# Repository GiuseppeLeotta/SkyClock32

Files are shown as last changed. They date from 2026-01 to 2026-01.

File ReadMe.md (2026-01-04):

# SkyClock

> **Time, atmosphere and the sky — on your table**

A stylish desk clock that shows the time with an analog-digital dial, monitors temperature, humidity and atmospheric pressure, records 24-hour trends with intuitive charts, and indicates sunrise and sunset times as well as the position of the Moon and the main planets. All accompanied by a gentle cuckoo every hour and bells at noon.

<p align="center">
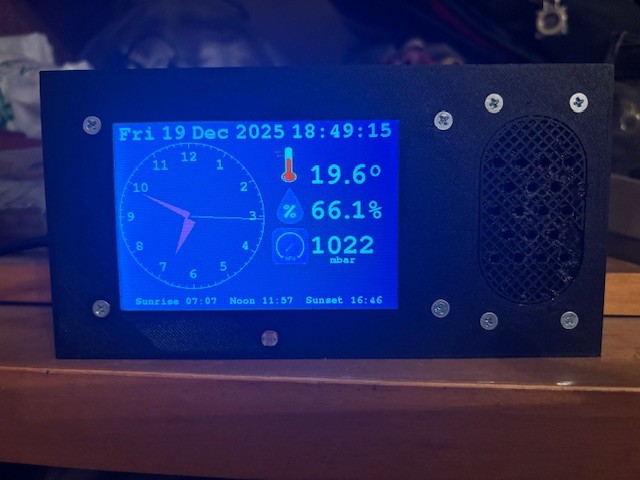
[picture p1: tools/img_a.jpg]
    
</p>

Bring to your table an object that tells the story of time and the sky. **SkyClock** combines a large, readable display with precision microclimate sensors and local astronomical calculations: sunrise/sunset times, the position of the Moon and the planets Mercury, Venus, Mars, Jupiter and Saturn. It records temperature, humidity and pressure trends over the last 24 hours and displays them with intuitive charts. A sweet cuckoo every hour; bells at noon. Set your preferred alarm and customize every aspect to your needs.

<p float="left" >
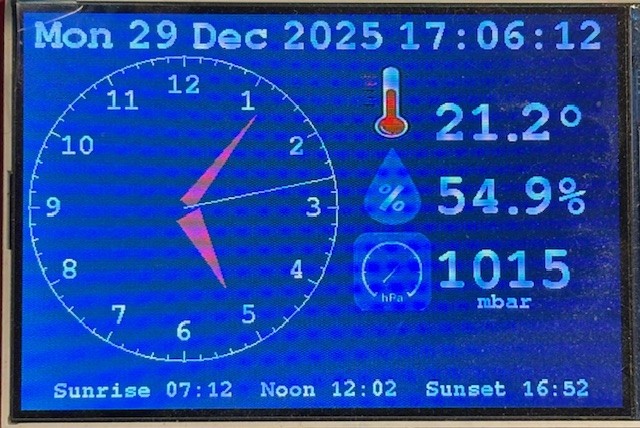
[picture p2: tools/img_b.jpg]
  
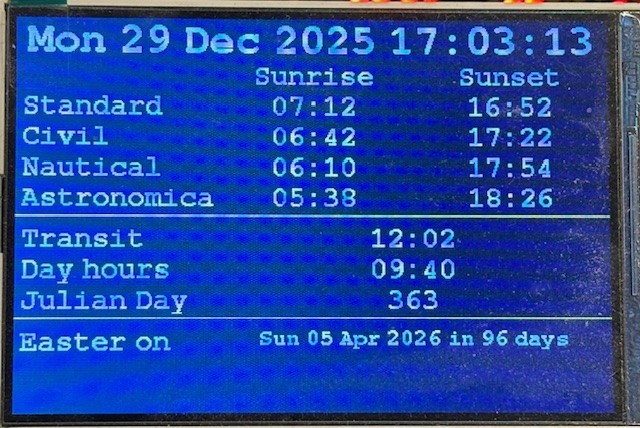
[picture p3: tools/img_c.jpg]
  
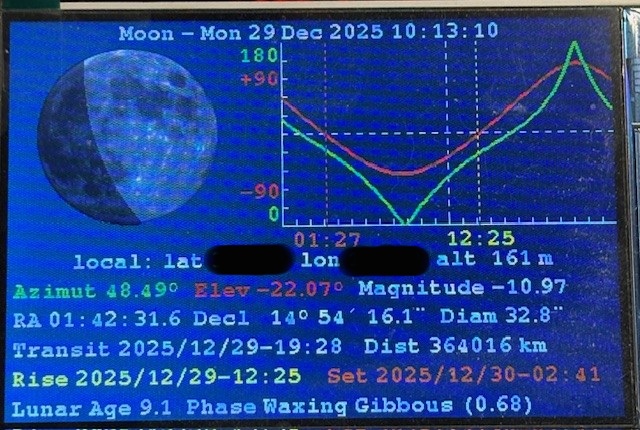
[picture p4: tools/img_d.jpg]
  
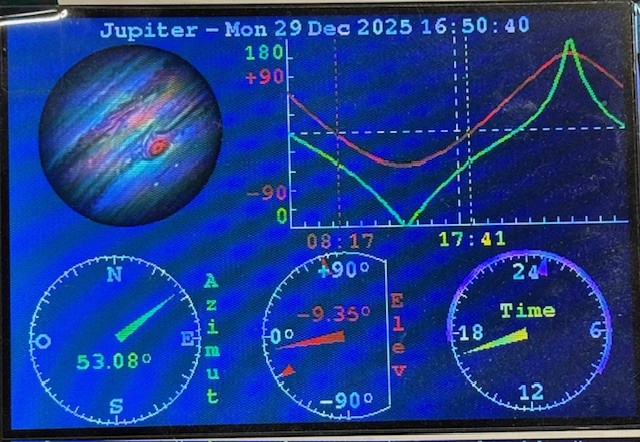
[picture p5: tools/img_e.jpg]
  
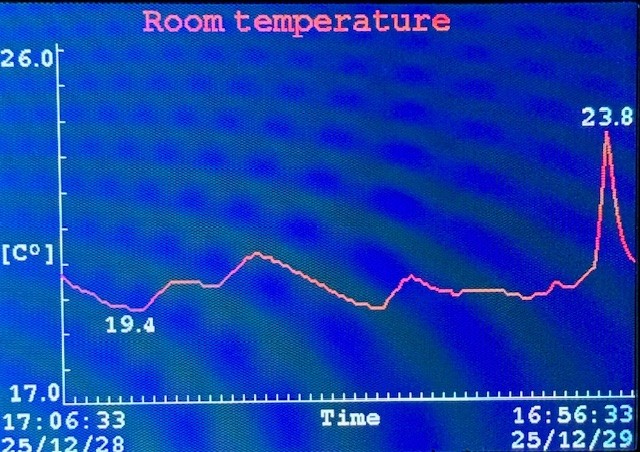
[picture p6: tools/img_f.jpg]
  
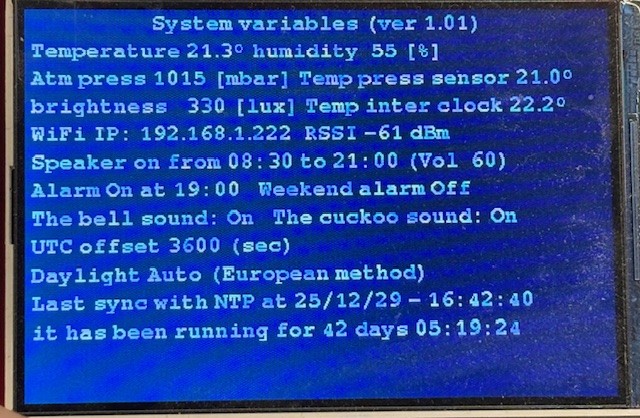
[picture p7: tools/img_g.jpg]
  
</p>

Here is a video showing what happens at noon; you will hear the bells ringing :smile:. Click on the image.

<p align="center">
  <a href="https://vimeo.com/1151204204" target="_blank" rel="noopener noreferrer">
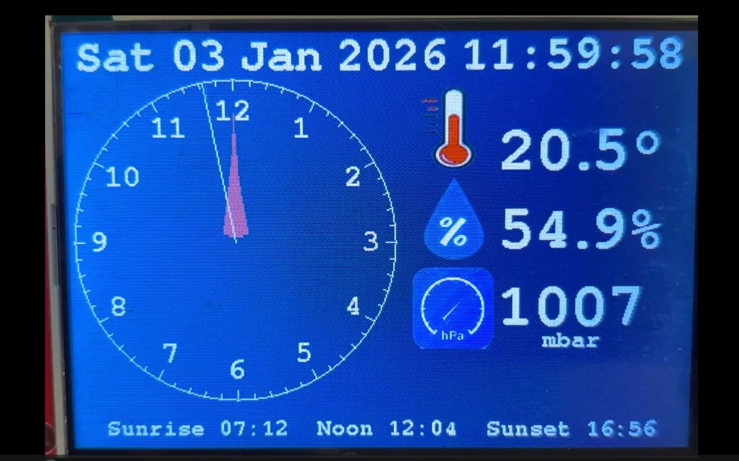
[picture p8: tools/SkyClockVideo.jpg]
SkyClockVideo — click to watch
    
  </a>
</p>

## Features

- **Main dial**: large analog-digital display with overlay readings of temperature, humidity and atmospheric pressure values.

- **Additional screens**: sunrise and sunset times and a simplified night sky map showing the position of the Moon and visible planets (Mercury, Venus, Mars, Jupiter, Saturn).

- **24h log**: automatic sampling and storage of environmental data with charts that can be viewed directly on the display.

- **Customizable chimes**: cuckoo every hour, bells at noon and configurable alarm. Sound activation options include the ability to disable the cuckoo during nighttime hours.

- **Setup via web server**: connect to **SkyClock** via WiFi and use your smartphone and a web browser to configure all parameters to your liking.

## Technical specifications

- **Display**: 4.0 Inch SPI TFT LCD Module 4.0" with ILI9488 driver, resolution 480×320 pixels and brightness control.
- **Sensors**: digital thermometer, hygrometer and precision barometer.
- **Memory**: rolling log of the last 24 hours, sampling every 30 seconds, storage every 10 minutes.
- **Astronomical calculation**: positions and times calculated locally from latitude and longitude. Calculation of sunrise/sunset, right ascension, declination, altitude, azimuth and magnitude. Moon phases with limb angle and parallax calculations.
- **Audio**: integrated speaker with cuckoo, bells and customizable alarm sounds; adjustable volume.
- **Power**: 5V adapter with backup battery to preserve the clock.
- **Connectivity**: WiFi, access point mode and automatic synchronization with NTP servers for maximum accuracy.

## Contents

- [Setup Guide](#setup-guide)
  - [List of Components](#list-of-components)
  - [Wiring](#wiring)
  - [Printed Circuit Board](#printed-circuit-board)
  - [3D Printer Box Creation](#3d-printer-box-creation)
- [Assembly](#assembly)
  - [Compilation](#compilation)
    - [FileSystem](#filesystem)
  - [How to assemble it](#how-to-assemble-it)
  - [Configuration](#configuration)
- [Warnings](#warnings)
- [Licensing](#licensing)
- [Disclaimer](#Disclaimer)

## Setup Guide

### List of Components

Here is the complete list of electronic components needed to build the project. The provided links are for indication only and to help you find the parts.

> ***WARNING***: the display must necessarily have the ILI9488 driver

| Component Type | Component | Link |
| --- | --- | --- |
| LCD TFT 4.0 inch | 4.0 inch SPI TFT LCD no touch screen 480×320 pixel color display _(1)_ | Available [here](https://it.aliexpress.com/item/1005006102051152.html) |
| SHT30 | Temperature humidity sensor | Available [here](https://it.aliexpress.com/item/1005006939280040.html) |
| MAX98357 | 3W Class D Amplifier Breakout Interface I2S Decoder DAC for Audio | Available [here](https://it.aliexpress.com/item/1005006711010527.html) |
| ESP32 | ESP32 38Pin CP2102 micro USB | Available [here](https://it.aliexpress.com/item/1005006351235505.html) |
| Speaker | PCS 3 Watt 8 Ohm Micro Speaker | Available [here](https://www.amazon.it/HUAREW-Altoparlante-interfaccia-JST-PH2-0-elettronici/dp/B0CRNZYW1R/) |
| DS3231 | AZDelivery Real Time Clock RTC DS3231 and Free Battery Included | Available [here](https://www.amazon.it/AZDelivery-Arduino-Raspberry-Microcontroller-AT24C32/dp/B076GP5B94/) |
| BMP180 | AZDelivery 3 x GY-68 BMP180 Barometric Pressure Sensor | Available [here](https://www.amazon.it/AZDelivery-Pressione-Barometrica-Raspberry-gratuito/dp/B07FRW7YTK/) |
| Button | 16mm Plastic Momentary Push Button Switch, Round Head Button | Available [here](https://www.amazon.it/QitinDasen-Interruttore-Pulsante-Momentaneo-Plastica/dp/B08GPFTJ4Q/) |
| PCB Connectors | 2.54mm Pitch 40 Pin Breakaway PCB Board | Available [here](https://www.amazon.it/Breakaway-Connettore-Intestazione-Connettori-Prototype/dp/B0DJ2MYFMB/) |
| GL5516 | Photoresistor 5 mm - 10 Lux: 5-10 kOhm, Dark Resistance: 0.5 MOhm | Available [here](https://www.amazon.it/qualit%C3%A0-GL5516-Light-Dependent-Resistor-Photoresistor/dp/B00NXW9WZ6/) |
| 4 resistors | 1/4 watt: n.2 → 4,7 kOhm, n.1 → 47 kOhm, n.1 → 10 kOhm | |
| Capacitor | 1000µF 16 Volt capacitor | |

_(1) Note: it is listed as driver ST7796S but actually mounts the ILI9488 chip_

### Wiring

Here is the complete electrical schematic for the project. Building it is relatively simple, but if you decide to wire it manually without using the PCB, pay close attention to component polarities to avoid damage.

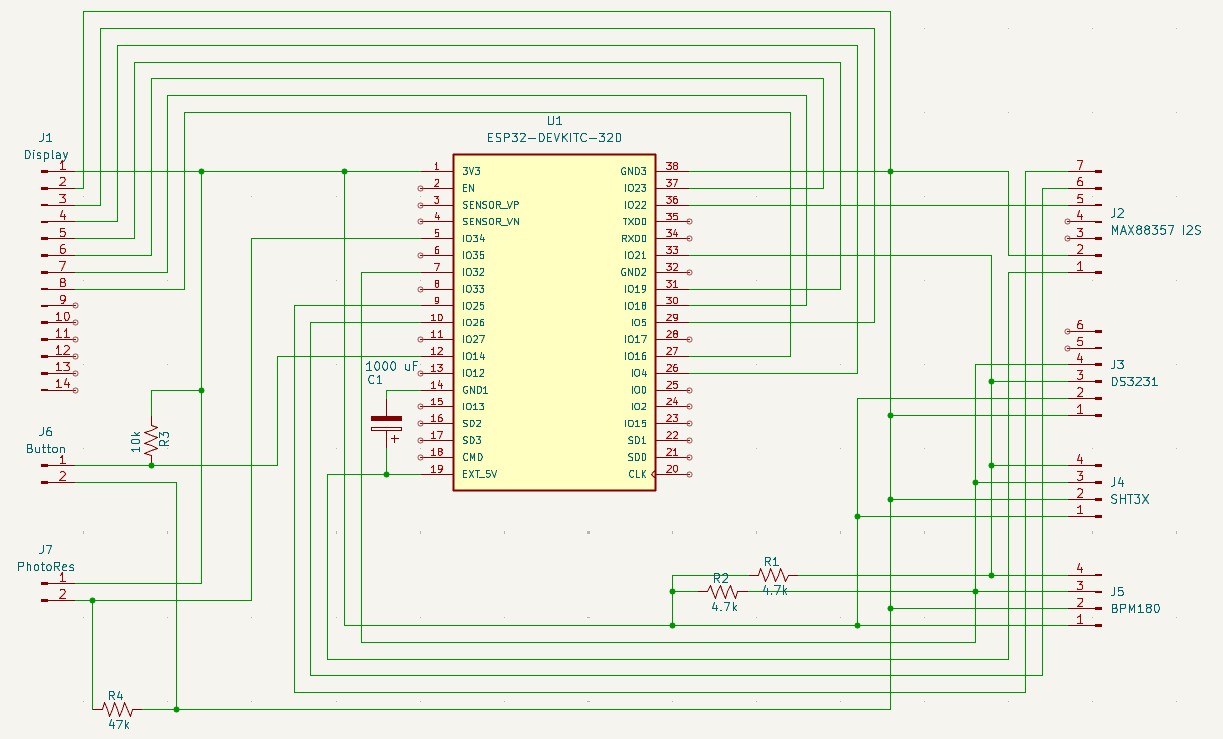
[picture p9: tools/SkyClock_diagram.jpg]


### Printed Circuit Board

The files needed to make the printed circuit board are available in this [folder](pcb/).

The printed circuit board is designed as a double-sided board. Pads were added for electrical connection between the Front and Back sides, making it possible to make the PCB even at home using a CNC milling machine. I personally use [FlatCAM](http://flatcam.org/) to generate .nc files to send to the CNC machine.

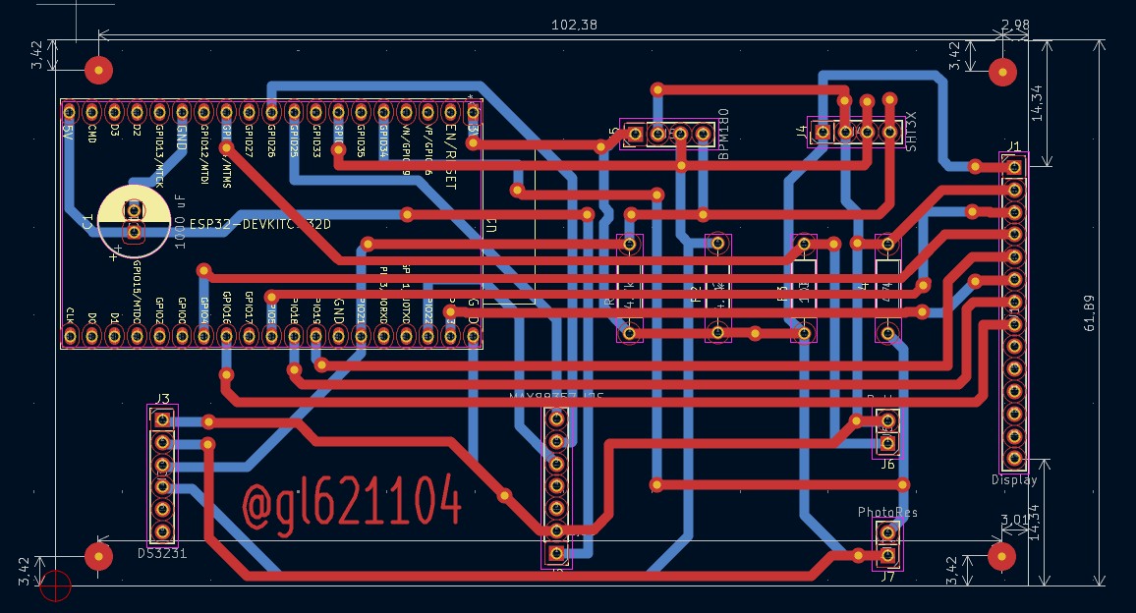
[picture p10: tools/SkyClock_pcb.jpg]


**Important note**: the PCB is prepared for soldering the display on the Front side. In this way the holes for supporting the PCB match exactly the holes of the display and those foreseen in the enclosure made with the 3D printer.

### 3D Printer Box Creation

To complete the project I designed an enclosure with [FreeCAD](https://www.freecad.org/) sized 165×85×45 mm to be made with a 3D printer. The enclosure was designed to perfectly host the PCB with the display connected, as you can see in the section [How to assemble it](#how-to-assemble-it).

<p float="left" >
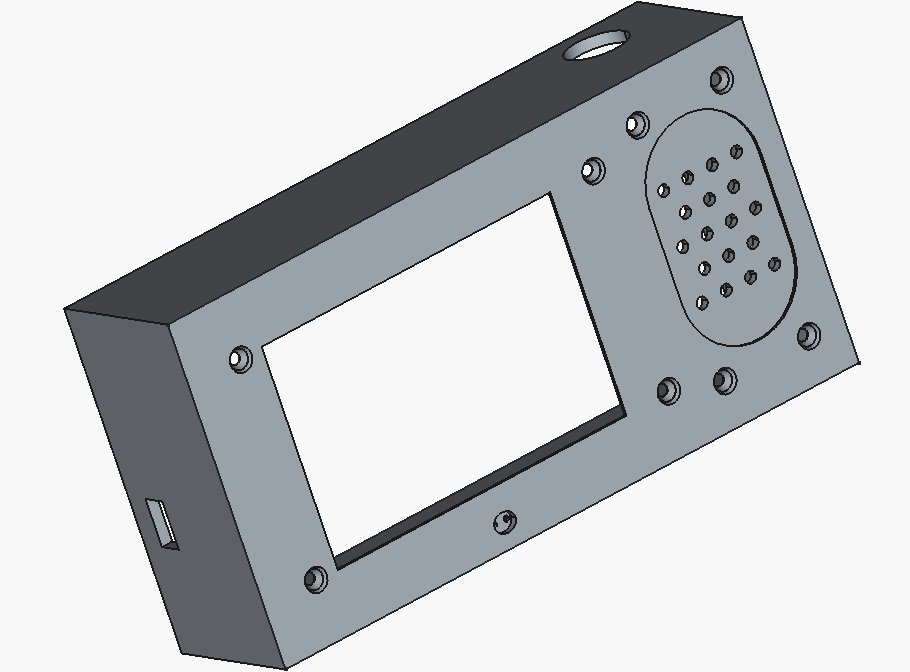
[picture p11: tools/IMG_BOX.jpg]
  
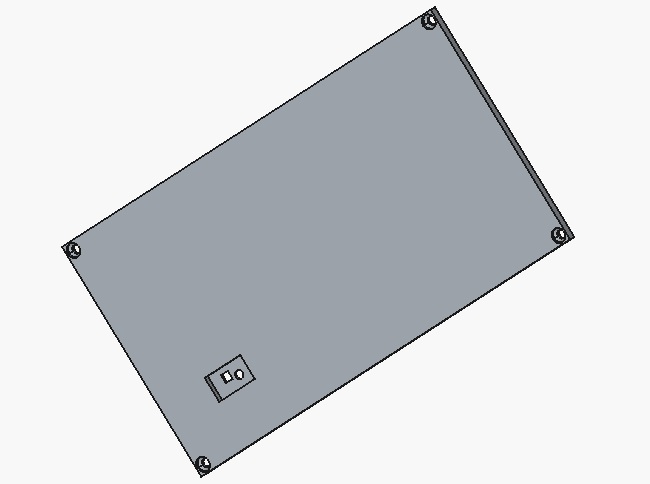
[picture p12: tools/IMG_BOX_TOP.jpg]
  
</p>

The .stl files are available in this [folder](print3d/). There are no particular criticalities in printer setup. I used the following settings with [Cura](https://ultimaker.com/software/ultimaker-cura/):

- Generic PLA
- 0.4 mm Nozzle
- Infill Density 30%
- Infill Pattern Cubic
- Support On
- Adhesion Off

The only important precaution is to enable supports (Support On) to avoid problems when creating the holes.

## Assembly

### Compilation

To compile the **SkyClock** software you need to have the [Arduino 2.x](https://docs.arduino.cc/software/ide-v2/tutorials/getting-started/ide-v2-downloading-and-installing/) IDE installed. First install support for ESP32. I recommend this tutorial: [Installing ESP32 Board in Arduino IDE 2](https://randomnerdtutorials.com/installing-esp32-arduino-ide-2-0/)

Next you need to install the driver for uploading the FileSystem. Again I recommend this tutorial: [Arduino IDE 2: Install ESP32 LittleFS Uploader](https://randomnerdtutorials.com/arduino-ide-2-install-esp32-littlefs/)

The code requires the [ESP8266Audio](https://github.com/earlephilhower/ESP8266Audio) library created by [earlephilhower (Earle F. Philhower, III)](https://github.com/earlephilhower). To install it go to 'LIBRARY MANAGER', search for ESP8266Audio and proceed with the installation.

<p align="center">
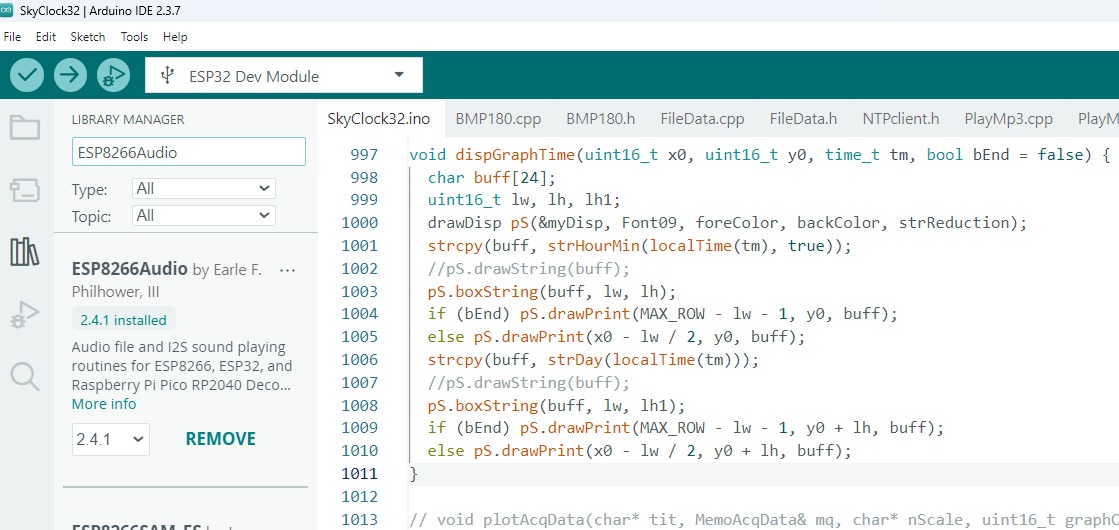
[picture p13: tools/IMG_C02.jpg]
  
</p>

Now we can proceed with compilation. Load the SkyClock32.ino file from the [SkyClock32](SkyClock32/) folder, select the board "ESP32 Dev Module" and Partition Scheme: "No OTA (2MB APP/2MB SPIFFS)".

<p align="center">
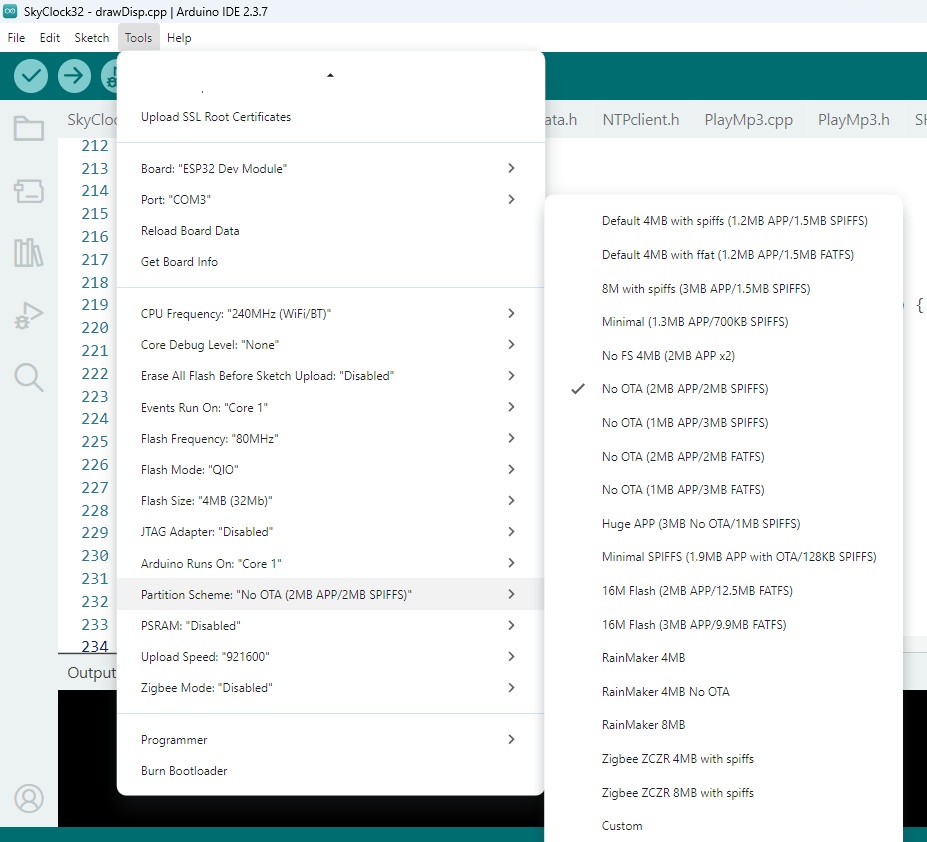
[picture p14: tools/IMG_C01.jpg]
  
</p>

At this point we can upload the data to the ESP32 filesystem (on Windows press [Ctrl] + [Shift] + [P]). All files present in the [data](SkyClock32/data) folder will be copied to the ESP32. After this step, compile and upload the program. Your **SkyClock** is ready to use!

#### FileSystem

In the [data](SkyClock32/data) folder are the files that will be copied into the ESP32 FileSystem. These are mainly .mp3 files for the noon bell sounds. There are 31 files that will be chosen randomly, one different for each day of the month, and then repeat the next month again randomly.

Of course you can change or add the sounds you prefer. The file name is not important (maximum 16 characters) but the extension must necessarily be .mp3. To avoid overloading the ESP32 memory it is recommended that files be mono with sampling at 8 kbps.

There is also the subfolder [as](SkyClock32/data/as) which contains 3 mp3 files. In this case the file naming is significant. You can modify their names inside the SkyClock32.ino code through the following constants:

```c
#define NAME_FILE_CUCU_PLAY "/as/CUCUCLK.mp3"
#define NAME_FILE_ALARM_CLOCK "/as/alarmClock1.mp3"
#define NAME_FILE_INIT_SOUND "/as/InitSound.mp3"
```

In particular these mp3 files are used for:

- `NAME_FILE_CUCU_PLAY` → plays the cuckoo every hour
- `NAME_FILE_ALARM_CLOCK` → is the alarm sound
- `NAME_FILE_INIT_SOUND` → is played only when **SkyClock** is turned on and is used to verify that the audio system is functioning correctly

### How to assemble it

Once the PCB and the enclosure have been made and all components soldered, we can proceed with final assembly. Get 3 mm screws with matching nuts. Length is not critical, just make sure it is longer than 10 mm (I used 15 mm screws). Also required are 4 screws of 30 mm which will be used to secure the display and the PCB.

The first component to mount is the speaker. The operation is not particularly difficult, but pay attention to the screws near the edges of the enclosure.

<p align="center">
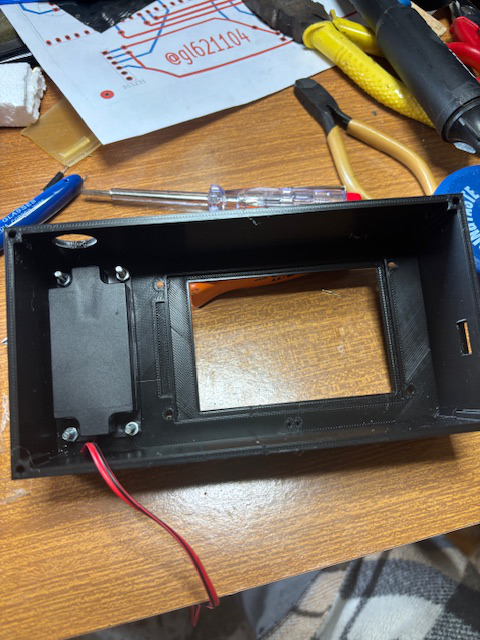
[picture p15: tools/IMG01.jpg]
    
</p>

Next mount the photoresistor. First cut the component leads to the right height (about halfway) so they can be inserted into the appropriate holes. If you prefer, you can simply solder them directly. A bit of adhesive tape will give stability to the connection.

<p align="center">
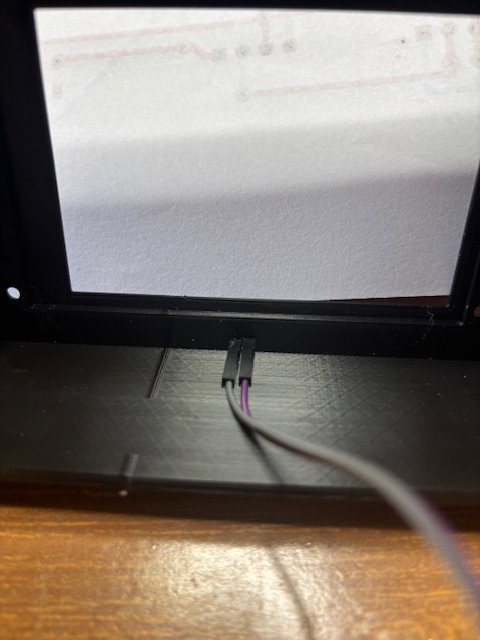
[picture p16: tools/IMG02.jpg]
  
</p>

Proceed with mounting the button, having previously soldered the electrical contacts. Pay attention during screwing, the nut is close to the speaker. Do not overtighten.

<p align="center">
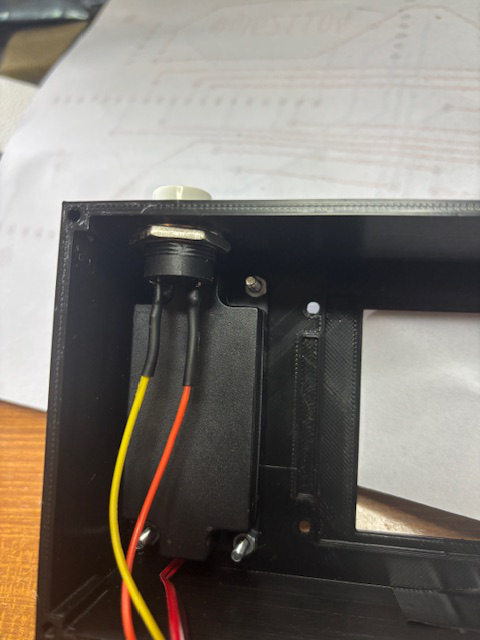
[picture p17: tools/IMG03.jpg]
    
</p>

Now move on to the most delicate part of the assembly. Use the 30 mm screws and insert the display so that the connectors face the speaker. Screw everything without over-tightening, leaving a small amount of play.

<p align="center">
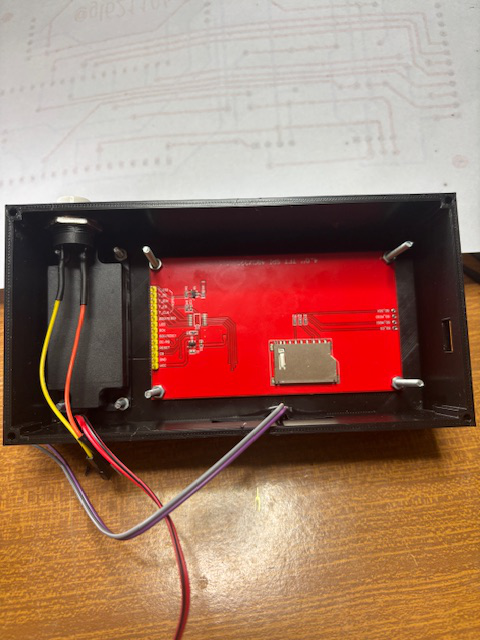
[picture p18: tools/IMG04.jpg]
    
</p>

Insert 4 nuts on the 30 mm screws, positioning them so they are perfectly flat and at the correct height to allow the display connectors to latch onto the PCB.

<p align="center">
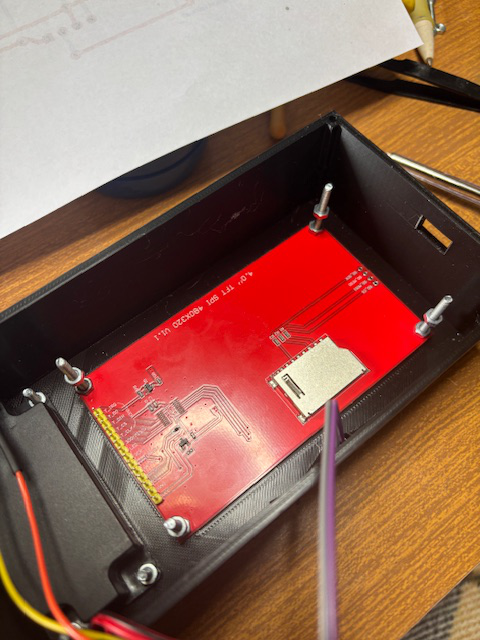
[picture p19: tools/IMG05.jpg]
    
</p>

At this point insert the PCB and attach the display. Check that the ESP32 mini-USB connector is perfectly aligned with the side hole of the enclosure so that the USB cable can be easily inserted. Secure everything with 4 more nuts.

<p align="center">
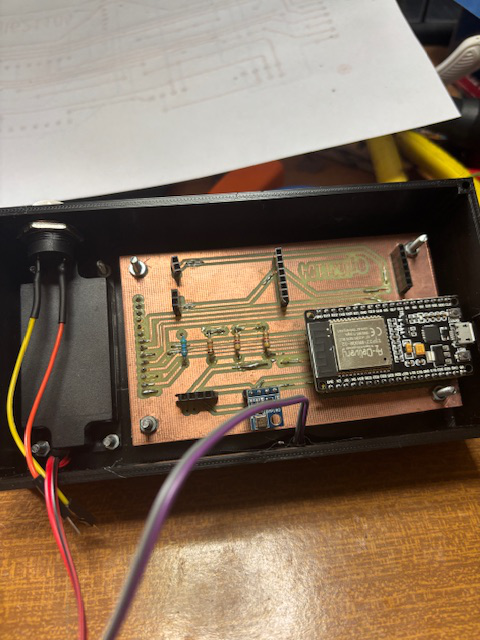
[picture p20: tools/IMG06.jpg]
  
</p>

Proceed to mount the SHT30 sensor in the enclosure lid. The grooves on the surface guide the insertion of the SHT30 into a single correct position. Fasten everything with a 10 mm screw.

<p align="center">
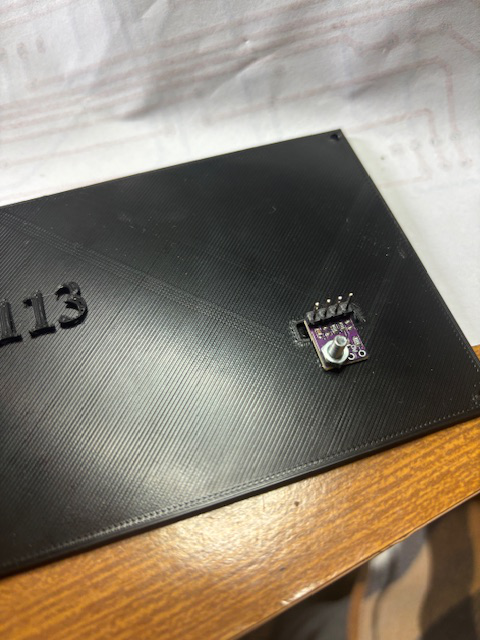
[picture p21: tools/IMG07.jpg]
    
</p>

If you want more accurate readings, you can insert a strip of expanded polystyrene to isolate the SHT30 sensor from the internal heat of the enclosure, making measurements more accurate.

<p align="center">
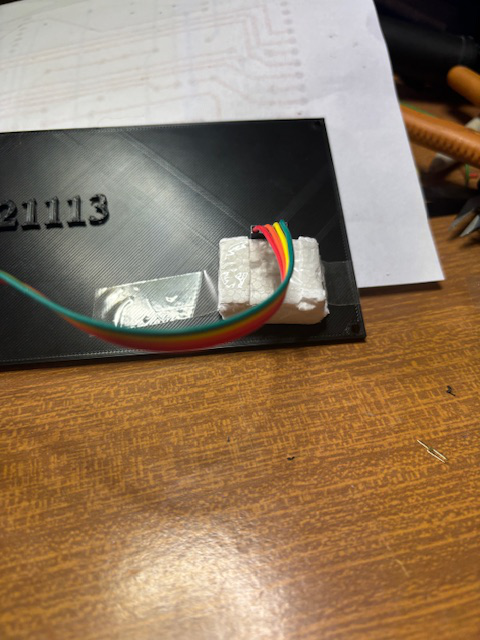
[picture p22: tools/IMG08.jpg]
  
</p>

Complete the assembly by making the final connections, paying **close attention to component polarities** to avoid damage.

<p align="center">
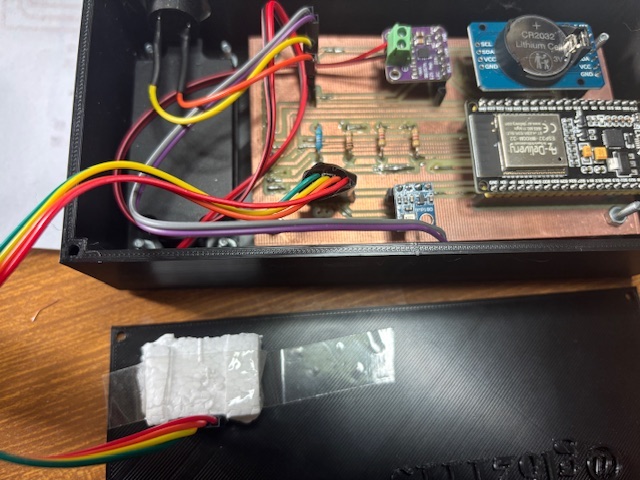
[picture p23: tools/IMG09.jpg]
    
</p>

### Configuration

There are two modes to configure **SkyClock**. The first allows you to change some parameters during normal operation using the built-in button. The second turns the ESP32 into a WiFi access point: by connecting to the network with SSID 'SkyClock' via a browser, you can configure all necessary parameters in a complete and intuitive way.

If we hold the button for at least 20 seconds, we enter the edit mode [Set Value](#set-value) to quickly change some parameters. To change the value of the selected variable (highlighted in green) just press the button quickly. To move to the next variable, hold the button a little longer. To go back continue holding the button, and to exit the edit screen continue holding it until the home screen is restored. The system may seem complicated to describe, but I assure you it is very intuitive to use! :smiley:

If we keep the button pressed for at least 30 seconds, we enter [Access point](#access-point) mode. In this case you will need to use a device such as a smartphone or tablet to access the full configuration interface.

#### Set Value

<p align="center">
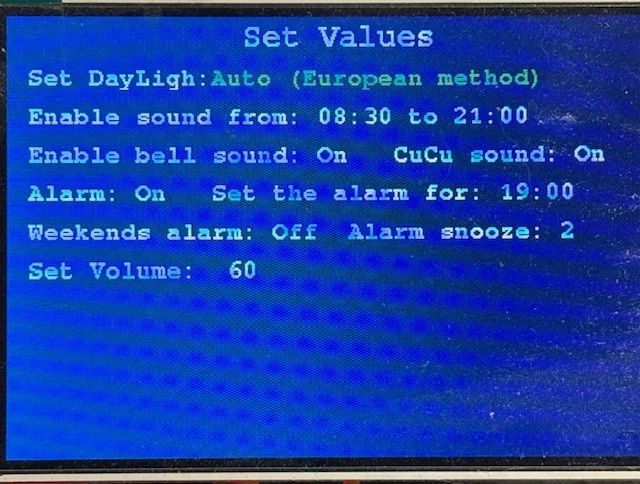
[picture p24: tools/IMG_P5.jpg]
  
</p>

Let's see the meaning of the available fields:

##### Set DayLight

Select daylight saving time handling. Three options are provided: the first enables automatic switching between standard/summer time according to the rules of the European Community, the other two allow manual enable/disable of daylight saving time.

##### Enable sound

Enables sounds for the selected time span. This function allows, for example, disabling the cuckoo during nighttime hours while keeping it active only during the day. The alarm is not affected by this setting and will ring at the scheduled time regardless.

##### Enable bell sound

Enables the noon bell sound every day. This function depends on the [Enable sound](#enable-sound) flag.

##### Cuckoo Sound

Enables the cuckoo sound every hour. This function also depends on the [Enable sound](#enable-sound) flag.

##### Alarm

Enables or disables the alarm.

##### Set the alarm for

Sets the alarm time.

##### Weekend alarm

Enable the alarm during the weekend. If you prefer not to be disturbed on Saturday and Sunday, set this flag to off.

##### Alarm snooze

Defines the number of times the alarm is automatically repeated. If you have difficulty waking up in the morning, increase this parameter! :smirk: In any case, the alarm sound can be stopped manually by pressing the button.

##### Set Volume

This parameter defines the sound volume. The range is 0 to 200. Keep in mind that at the maximum value of 200 the sound saturates. The recommended ideal value is 100.

#### Access point

After holding the button for at least 30 seconds, the following screen will appear on the display:

<p align="center">
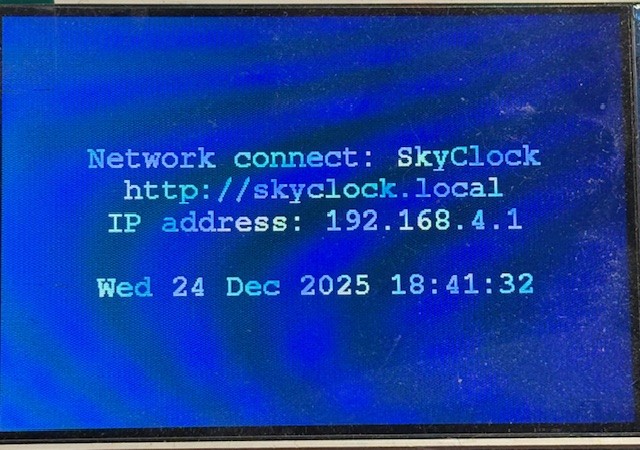
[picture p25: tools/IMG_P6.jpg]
  
</p>

Connect with the WiFi of your tablet or smartphone to the network with SSID **SkyClock** (no password required). Using one of the available browsers, type skyclock.local or, if you prefer, the direct IP address: 192.168.4.1. You will get the following configuration interface:

<p float="left" >
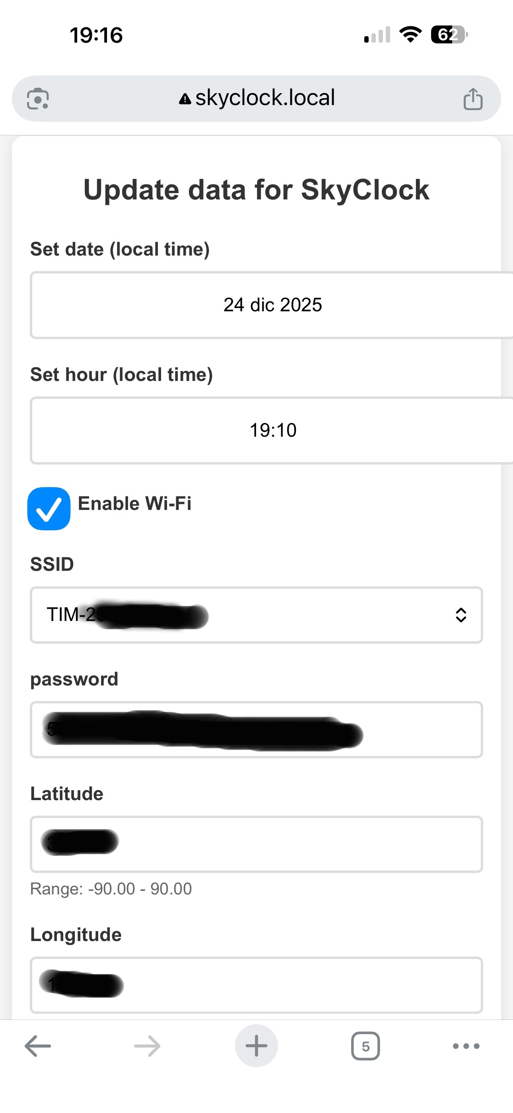
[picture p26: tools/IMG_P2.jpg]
  
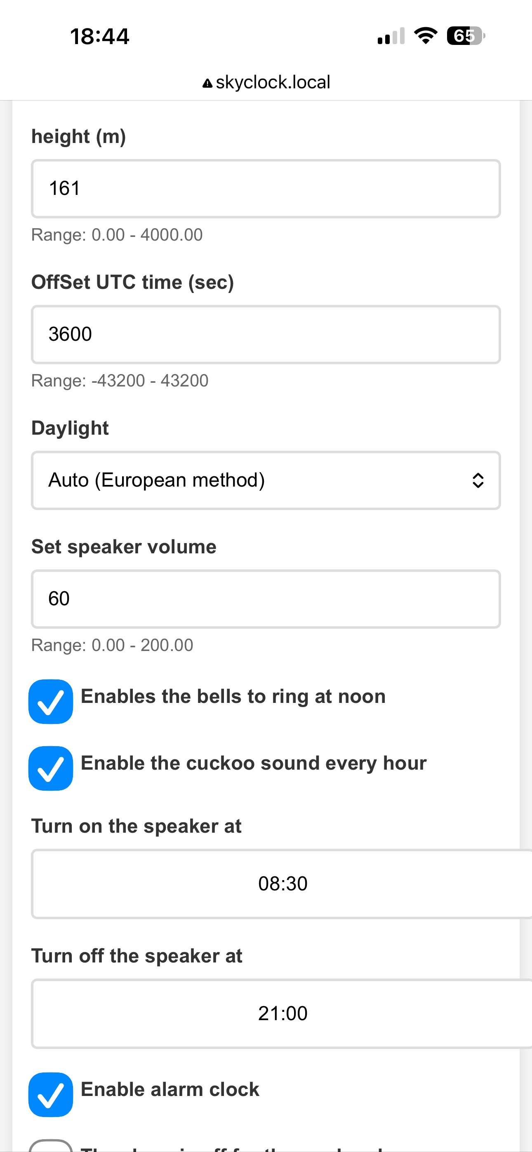
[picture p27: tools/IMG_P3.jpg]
  
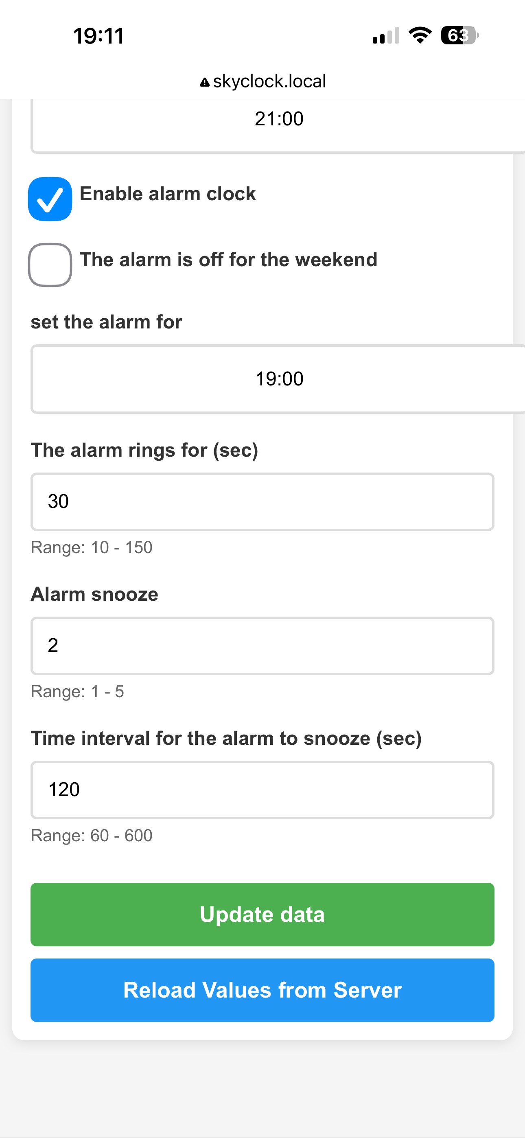
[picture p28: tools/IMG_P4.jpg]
  
</p>

Let's see the meaning of the available parameters:

##### Set Date - Set Hour

Set the local date and time manually. If the [Enable Wi-Fi](#enable-wi-fi) flag is disabled, the internal clock of **SkyClock** will be configured with these manually entered values.

##### Enable Wi-Fi

Enables WiFi connection. This function is used to automatically connect **SkyClock** to NTP (Network Time Protocol) servers approximately every 24 hours, ensuring maximum time precision. If you do not have a WiFi network, disable this flag: **SkyClock** accuracy will still be maintained by the DS3231 RTC module.

##### SSID - password

These are the parameters required to connect to your home WiFi network. If the [Enable Wi-Fi](#enable-wi-fi) flag is disabled, these values will not be considered.

##### Latitude - Longitude - height

These parameters define the precise geographic location where **SkyClock** is located. All astronomical calculations (sunrise, sunset, position of Moon and planets) use these values. Pay attention to extreme latitude values: beyond ±83 degrees astronomical calculations may present significant errors.

##### Offset UTC time

This parameter defines the difference in seconds between local time and Coordinated Universal Time (UTC). All astronomical calculations are performed using UTC and then converted to local time through this parameter and the [Set DayLight](#set-daylight) flag value. For example, if you live in Rome, which is one hour ahead of UTC, the value to enter is 3600 (i.e. one hour expressed in seconds).

##### The alarm ring for

This parameter defines the maximum duration in seconds of the alarm sound before it turns off automatically.

##### Time interval for the alarm to snooze

This parameter specifies the time interval in seconds between one alarm repetition and the next. The total number of repetitions is defined by the [Alarm snooze](#alarm-snooze) parameter.

##### Other Parameters

These parameters have already been described in detail in the [Set Value](#set-value) section. Here is the complete list of correspondences:

- Daylight → [Set DayLight](#set-daylight)
- Set Speaker volume → [Set Volume](#set-volume)
- Enables the bells to ring at noon → [Enable bell sound](#enable-bell-sound)
- Enable the cuckoo sound every hour → [Cuckoo Sound](#cuckoo-sound)
- Turn on/off the speaker at → [Enable sound](#enable-sound)
- Enable alarm clock → [Alarm](#alarm)
- The alarm is off for the weekend → [Weekend alarm](#weekend-alarm)
- Set alarm for → [Set the alarm for](#set-the-alarm-for)
- Alarm snooze → [Alarm snooze](#alarm-snooze)

## Warnings

Building this project requires a minimum of experience with embedded systems. It's not exceptionally complicated, but you need to be familiar with using a soldering iron and the basic principles of electronics. :grinning:

The code may contain errors which I will correct as they are found. I invite you to report any problems or bugs through the repository issues.

Astronomical calculations are performed with good accuracy, although a margin of error of a couple of minutes on sunrise and sunset times should be considered normal and acceptable. Pay special attention for extreme latitudes beyond ±83 degrees: I have not been able to carry out extensive tests at these latitudes, so there is a remote possibility that some algorithms diverge or that calculation precision is not sufficient. For reference, the Svalbard islands are at about 78 degrees North... do you know anyone who lives further north? :wink:

The code development was done in my spare time, so it has not been developed continuously. This inevitably led to different approaches in writing the code. I apologize if the result appears fragmented, not sufficiently commented, or if you find Italian comments scattered here and there.

## Licensing

This program is free software: you can redistribute it and/or modify it under the terms of the [GNU General Public License v3.0](https://www.gnu.org/licenses/gpl-3.0.html) published by the Free Software Foundation, either version 3 of the License, or (at your option) any later version.

This code and all related parts (electrical schematic, PCB, 3D printing files, etc.) are distributed "as is" in the hope that they may be useful, but **WITHOUT ANY WARRANTY**, not even the implied warranty of MERCHANTABILITY or FITNESS FOR A PARTICULAR PURPOSE. See the GNU General Public License for more details.

All images used in the project were created via Python software I developed, using as a base freely licensed images downloaded from the internet.

Fonts use the [GFXglyph](https://github.com/adafruit/Adafruit-GFX-Library/blob/master/gfxfont.h) structure developed by [Adafruit](https://github.com/adafruit/Adafruit-GFX-Library) under the BSD license.

The [fonts](SkyClock32/Fonts) used in this software were derived from [fonts/gnu-freefont_freemono](https://github.com/opensourcedesign/fonts/tree/master/gnu-freefont_freemono) licensed under the [SIL Open Font License](https://openfontlicense.org/) and subsequently modified through the [freetype](https://github.com/ubawurinna/freetype-windows-binaries/tree/master) library.

All sounds were downloaded from [Freesound](https://freesound.org/) and then edited and adapted to the system using [Audacity](https://www.audacityteam.org/).

This software requires the [ESP8266Audio](https://github.com/earlephilhower/ESP8266Audio) library created by [earlephilhower (Earle F. Philhower, III)](https://github.com/earlephilhower).

## Disclaimer

This entire project is released under the GPL license and its use and construction are at your own risk. If you find bugs, please report them via the GitHub issue tracker or send me an email

## 💖 Support the Project

This project is developed and maintained in my free time and is completely free and open source. Development involves costs for hardware, testing, and hosting. If you find it useful and want to support its continued development, consider buying me a coffee!



Every contribution is greatly appreciated and helps cover development costs and allows me to dedicate more time to this and other IoT projects. Thank you! ☕

Giuseppe Leotta

g.leotta63@hotmail.com

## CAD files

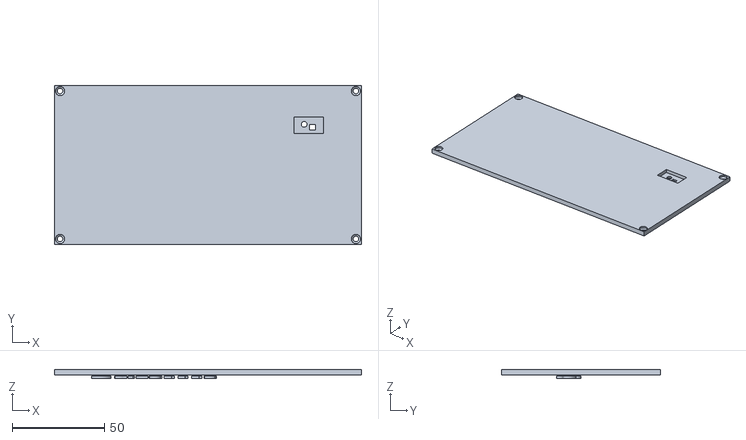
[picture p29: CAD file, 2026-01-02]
print3d/skyclock32v01_top.stl
166.0 x 86.0 x 5.00

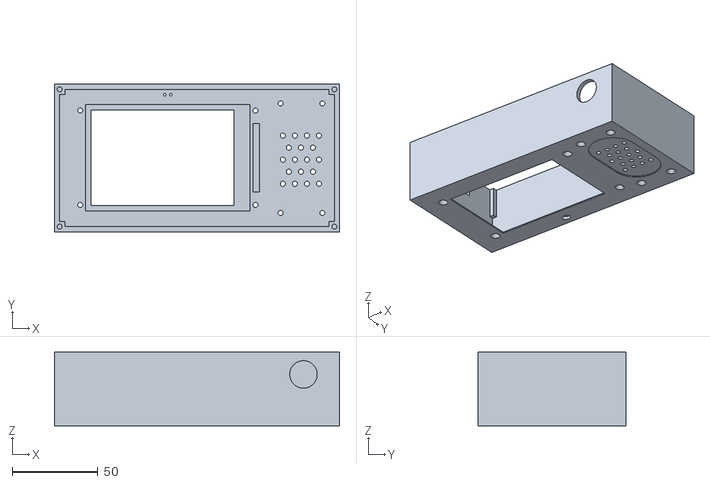
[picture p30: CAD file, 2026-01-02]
print3d/skyclock32v01.stl
166.0 x 86.0 x 43.0

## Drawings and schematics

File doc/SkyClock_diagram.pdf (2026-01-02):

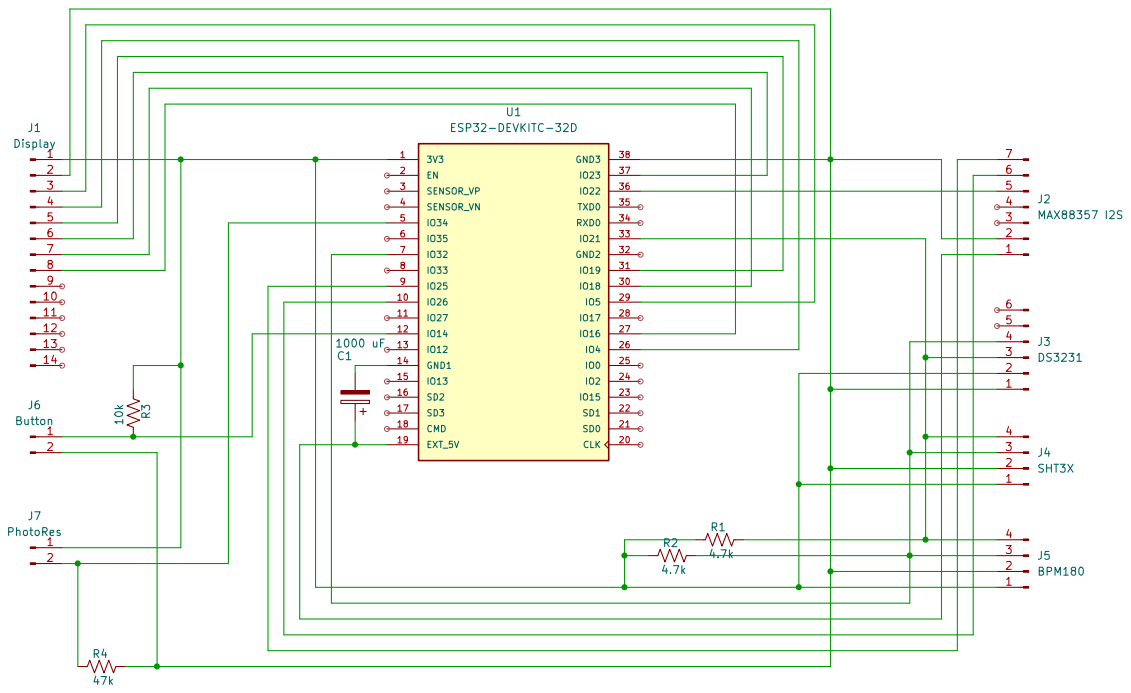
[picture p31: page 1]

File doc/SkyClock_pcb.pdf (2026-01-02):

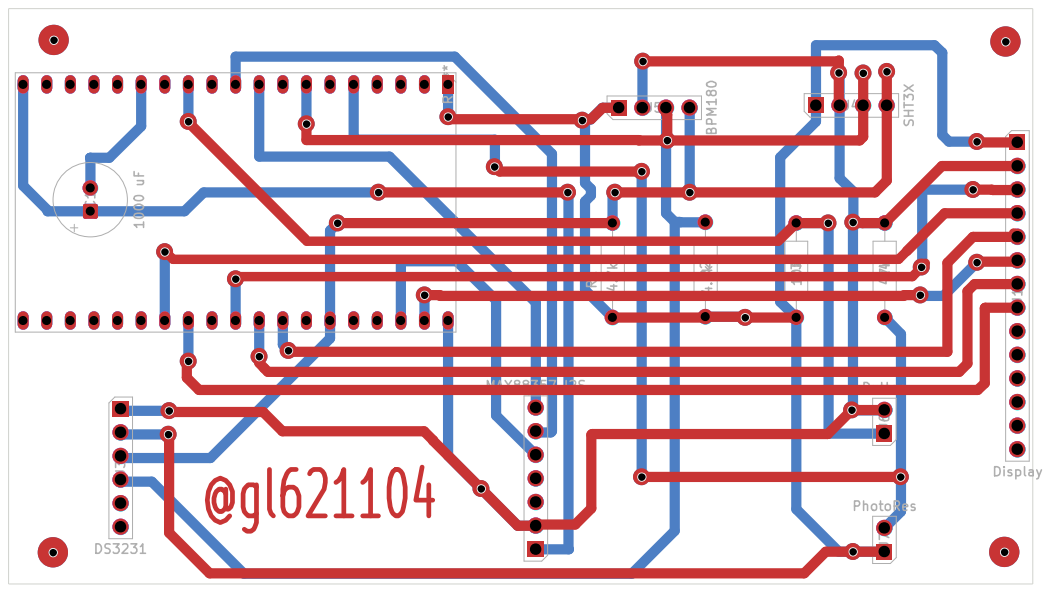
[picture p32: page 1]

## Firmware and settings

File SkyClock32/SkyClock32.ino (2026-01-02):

#include <arduino.h>
#include <time.h>
#include <SPI.h>
#include <WiFi.h>
#include <WiFiUdp.h>



#include "dispILI9488.h"
#include "drawDisp.h"
#include "drawClock.h"
#include "NTPclient.h"
#include "FileData.h"
#include "Button.h"
#include "PlayMp3.h"
#include "uRandom.h"
#include "ds3231.h"
#include "BMP180.h"
#include "SHT30.h"
#include "SolarSys.h"
#include "cAverage.h"
#include "editVar.h"
#include "utility.h"
#include "structDataPrg.h"
#include "editVarWeb.h"


#include "gImage.h"
#include "dataTermoImg.h"
#include "dataUmiImg.h"
#include "dataPressImg.h"
#include "dataSunImg.h"
#include "dataMoonImg.h"
#include "dataMercuryImg.h"
#include "dataVenusImg.h"
#include "dataMarsImg.h"
#include "dataJupiterImg.h"
#include "dataSaturnImg.h"


const float Version = 1.01;  // SkyClock version

#define I2S_SCK 26
#define I2S_WS 25
#define I2S_OUT 22

#define SPI_CLK 18
#define SPI_MOSI 23
#define SPI_CS 5
#define SPI_RST 4
#define SPI_DS 19

#define I2C_SDA 21
#define I2C_SCL 32

#define PIN_DISP_LED 16

#define PIN_BUTT 14

#define PIN_PHOTO_R 34

#define PWM_FREQ 5000
#define PWM_RESOLUTION 8


const uint16_t MAX_COL = 320;
const uint16_t MAX_ROW = 480;

const char* strReduction = " .";
const GFXfont* Font09 = &FreeMonoBold9pt8b;
const GFXfont* Font12 = &FreeMonoBold12pt8b;
const GFXfont* Font18 = &FreeMonoBold18pt8b;
const GFXfont* Font24 = &FreeMonoBold24pt8b;

#define NAME_FILE_CUCU_PLAY "/as/CUCUCLK.mp3"
#define NAME_FILE_ALARM_CLOCK "/as/alarmClock1.mp3"
#define NAME_FILE_INIT_SOUND "/as/InitSound.mp3"


char* strDayLigh[] = { "Solar", "Legal", "Auto (European method)" };


// press [Ctrl] + [Shift] + [P] to open the command palette

typedef void (*CallbackPos)(double jd, Observer& obs, CelestialPosition& pos);
typedef int (*CallbackRiseSet)(double jd, Observer& obs, const double horizon, RiseSet& Twilight);

tagDataPrg DataPrg;

Observer obs;

#define TIME_SYNC_CLOCK (24 * 60 * 60UL * 1000UL)

// sync ogni 24 ore, timeout risposta 5 secondi
NTPClientNB ntp("pool.ntp.org", 123, TIME_SYNC_CLOCK, 5000);

SPIClass* vspi = new SPIClass(VSPI);

dispILI9488 myDisp(vspi, MAX_COL, MAX_ROW, SPI_DS, SPI_CS, SPI_RST);

#define BMP180_ADDR 0x77

BMP180 bm180(Wire, BMP180_ADDR, 3);
SHT30 sht(Wire);

uRandom urn;

#define NUM_POINT_ACQ 144
#define TIME_POINT_ACQ 600


MemoAcqData tempAmb(NUM_POINT_ACQ, TIME_POINT_ACQ, 10);
MemoAcqData umiAmb(NUM_POINT_ACQ, TIME_POINT_ACQ, 1);
MemoAcqData pressAmb(NUM_POINT_ACQ, TIME_POINT_ACQ, 1);

float tempExt = 0;
float umiExt = 0;
float pressExt = 0;
float tempInt = 0;
float luxExt = 0;
float tempClock = 0;
bool ErrTemp = false;
bool ErrPress = false;

const uint16_t backColor = 0x0bb4;
const uint16_t foreColor = RGB565_WHITE;

const uint16_t colorStrSet = RGB565_ORANGE;
const uint16_t colorStrRise = RGB565_YELLOW;


char** listFileMp3;    // lista per file mp3
int countFileMp3 = 0;  // numero di file mpe


bool IsDaylight = false;  // True is Daylight

#define PIXEL_TICK 4
#define NUM_POINT_GRAPH 130
#define SEC_POINT_GRAPH 720
#define AXIS_GRID_TICK 5
#define AXIS_RS_LINE 3

const uint16_t ColorLineAz = RGB565_GREEN;
const uint16_t ColorLineEl = RGB565_RED;



const uint16_t nxTick = 24;
const uint16_t nyTick = 10;

#define PIX_NEWLINE 23
#define PIX_NEWLINE01 25


#define NUM_SKY_OBJ 7

typedef struct tagCelPos {
  float el[NUM_POINT_GRAPH];
  float az[NUM_POINT_GRAPH];
  double t[NUM_POINT_GRAPH];
  time_t tm;
} CelPos;

CelPos plotCelPos[NUM_SKY_OBJ];


void PlotCelestialPosition(uint16_t x0, uint16_t y0, uint16_t lx, uint16_t ly, time_t tm, CallbackPos cb, RiseSet& TwGraph, CelPos& pC) {
  drawDisp axis(&myDisp, Font09, foreColor, backColor);
  uint16_t x1 = lx - 1, y1 = ly - 1;
  axis.axis(lx, ly, nxTick, nyTick, PIXEL_TICK, AXIS_GRID_TICK);

  CelestialPosition pos;

  if (tm - pC.tm > 360) {
    pC.tm = tm;
    for (int i = 0; i < NUM_POINT_GRAPH; i++) {
      pC.t[i] = tm - 13 * 3600 + SEC_POINT_GRAPH * i;
      double jd = time2jd(pC.t[i]);
      //SunPosition(jd, obs, pos);
      cb(jd, obs, pos);
      pC.el[i] = pos.el;
      pC.az[i] = (pos.az > 180 ? 360 - pos.az : pos.az);
      pC.t[i] = localTime(pC.t[i]);
    }
  }

  axis.plot(NUM_POINT_GRAPH, pC.t, pC.el, pC.t[0], pC.t[NUM_POINT_GRAPH - 1], -90, 90, ColorLineEl, 2);
  axis.plot(NUM_POINT_GRAPH, pC.t, pC.az, pC.t[0], pC.t[NUM_POINT_GRAPH - 1], 0, 180, ColorLineAz, 2);
  axis.refresh(x0, y0);

  drawDisp pS(&myDisp, Font09, foreColor, backColor, strReduction);
  char buff[16];
  uint16_t lw, lh, x, px, opx=0, olw=0;
  time_t tRS;
  if (TwGraph.polar == 0) {

    //Serial.printf(" rise %s\n", jd2str(localTimeJD(TwGraph.rise)));
    //Serial.printf(" transit %s\n", jd2str(localTimeJD(TwGraph.transit)));
    //Serial.printf(" set %s\n", jd2str(localTimeJD(TwGraph.set)));
    
    tRS = localTime(jd2time(TwGraph.rise));
    sprintf(buff, jd2str(localTimeJD(TwGraph.rise), true));
    pS.boxString(buff, lw, lh);
    myDisp.fillScreen(x0, y0 + ly + 1, MAX_ROW, y0 + ly + 1 + lh, backColor);

    //Serial.printf("rise %d %d\n", tRS >= pC.t[0], tRS <= pC.t[NUM_POINT_GRAPH - 1]);
    if (tRS >= pC.t[0] && tRS <= pC.t[NUM_POINT_GRAPH - 1]) {
      pS.creatCanvas(1, ly);
      pS.drawVerticalLine(0, 0, ly, AXIS_RS_LINE);
      pS.setColor(colorStrRise, backColor);
      x = pS.dScale(tRS, 0, lx - 1, pC.t[0], pC.t[NUM_POINT_GRAPH - 1]);
      //x=(x>=lx ? lx-1 : x);
      pS.refresh(x0 + x, y0);
      //sprintf(buff, jd2str(localTimeJD(TwGraph.rise), true));
      //pS.boxString(buff, lw, lh);
      //myDisp.fillScreen(0, y0 + ly + 1, MAX_ROW, y0 + ly + 1 + lh, backColor);
      //pS.drawString(buff);
      px = x0 + x;
      if (px + lw / 2 >= MAX_ROW) px = MAX_ROW - lw - 1;
      else px -= lw / 2;
      if (x0>px) px=x0+1;
      pS.drawPrint(px, y0 + ly + 1, buff);
      opx=px; olw=lw;
    }
    tRS = localTime(jd2time(TwGraph.set));
    //Serial.printf("set %d %d\n", tRS >= pC.t[0], tRS <= pC.t[NUM_POINT_GRAPH - 1]);
    if (tRS >= pC.t[0] && tRS <= pC.t[NUM_POINT_GRAPH - 1]) {
      pS.creatCanvas(1, ly);
      pS.drawVerticalLine(0, 0, ly, AXIS_RS_LINE);
      pS.setColor(colorStrSet, backColor);
      x = pS.dScale(tRS, 0, lx - 1, pC.t[0], pC.t[NUM_POINT_GRAPH - 1]);
      pS.refresh(x0 + x, y0);
      sprintf(buff, jd2str(localTimeJD(TwGraph.set), true));
      pS.boxString(buff, lw, lh);
      //pS.drawString(buff);
      px = x0 + x;
      if (px + lw / 2 >= MAX_ROW) px = MAX_ROW - lw - 1;
      else px -= lw / 2;
      if (x0>px) px=x0+1;
      if ((px>=opx || px+lw>=opx) && px<=opx+olw) pS.drawPrint(px, y0 + 4, buff);
      else pS.drawPrint(px, y0 + ly + 1, buff);
    }
  }

  pS.setColor(ColorLineAz, backColor);
  sprintf(buff, "180");
  pS.boxString(buff, lw, lh);
  //pS.drawString(buff);
  pS.drawPrint(x0 - (lw + 1), y0 + 1, buff);
  sprintf(buff, "0");
  pS.boxString(buff, lw, lh);
  //pS.drawString(buff);
  pS.drawPrint(x0 - (lw + 1), y0 + ly - (lh + 1), buff);
  pS.setColor(ColorLineEl, backColor);
  sprintf(buff, "+90");
  pS.boxString(buff, lw, lh);
  //pS.drawString(buff);
  pS.drawPrint(x0 - (lw + 1), y0 + 2 + lh, buff);
  sprintf(buff, "-90");
  pS.boxString(buff, lw, lh);
  //pS.drawString(buff);
  pS.drawPrint(x0 - (lw + 1), y0 + ly - 2 * (lh + 1), buff);
}

void GraphClock(time_t tm, uint32_t ms) {  // localtime --> ora GMT0
  static uint32_t do40 = 0;
  static time_t tm40 = 0;
  drawClock pClock(&myDisp, Font12, foreColor, backColor);
  const uint16_t cx = 125, cy = 125, radius = 124, long_tick = 8, short_tick = 4, posx = 3, posy = 33;

  if (tm != tm40) {
    do40 = 0;
    tm40 = tm;
  }
  int nCanvas = pClock.drawCircleClock(cx, cy, radius, long_tick, short_tick);
  pClock.drawHour(tm, RGB565_LIGHT_RED);
  pClock.drawMinute(tm, RGB565_LIGHT_RED);
  pClock.setCanvas(nCanvas);
  pClock.drawSecond(tm, do40);
  pClock.setPriority(nCanvas, 2);

  pClock.refresh(posx, posy);

  do40 += millis() - ms;
  do40 = (do40 > 1000 ? 0 : do40);
}


void playBell(void) {
  if (InRunMp3() == 0 && countFileMp3) {
    int16_t num;
    if (urn.hasNext()) {
      num = urn.next();
      Serial.printf("Estratto: %d (restanti: %u)\n", num, urn.remaining());
    } else {
      Serial.println("Tutti i numeri sono stati estratti.");
      Serial.println("Reset estrazioni...");
      urn.reset();
      num = urn.next();
    }
    Serial.printf("%d) name=%s\n", num, listFileMp3[num]);
    OpenMp3File(listFileMp3[num]);
  }
}

#define INTER_ACQ_DATA 15000  // millisec

bool AcqData(double rValue) {
  bool ret = false;
  static waitTimer tmAcqData(INTER_ACQ_DATA);
  if (!tmAcqData.run()) {
    tmAcqData.start();
    float p;
    auto r = sht.read();
    if (r.valid) {
      tempExt = r.temperature;
      umiExt = r.humidity;
      ErrTemp = false;
      //Serial.printf("%f %f\n",t,u);
    } else {
      Serial.printf("STH30 Error read\n");
      ErrTemp = true;
    }
    if (bm180.isConnected()) {
      tempInt = bm180.readTemperature();
      p = bm180.readPressure();
      pressExt = bm180.seaLevelPressure(p, DataPrg.height, tempExt);
      //Serial.printf("%f %f\n",tp,p);
      ErrPress = false;
    } else {
      Serial.printf("BMP180 Error read\n");
      ErrPress = true;
    }
    tempClock = readTemperatureDs3231();
    //Serial.printf("Acq data\n");
    ret = true;
  }
  luxExt = (float)valueLux(rValue);
  return ret;
}


void dpDigTime(time_t ltm) {
  drawDisp ph(&myDisp, Font18, foreColor, backColor, strReduction);
  ph.drawPrint(9, 0, strTimeAll(ltm));
}

void gPrintClock(time_t ltm) {  // localtime --> ora GMT0
  char buff[64];
  dpDigTime(ltm);
  drawDisp pS(&myDisp, Font24, foreColor, backColor, strReduction);
  sprintf(buff, "%3.1f\260", tempExt);
  //pS.drawString(buff);
  pS.drawPrint(330, 65, buff);
  sprintf(buff, "%3.1f%%", umiExt);
  //pS.drawString(buff);
  pS.drawPrint(330, 125, buff);
  sprintf(buff, "%4.0f", pressExt);
  //pS.drawString(buff);
  pS.drawPrint(330, 185, buff);
}


void gPrintRS(RiseSet Twilight) {
  char buff[64];
  uint16_t lw, lh;
  drawDisp ph(&myDisp, Font09, foreColor, backColor);
  if (Twilight.polar == 0) {
    char b1[24], b2[24];
    strcpy(b1, jd2str(localTimeJD(Twilight.transit), true));
    strcpy(b2, jd2str(localTimeJD(Twilight.set), true));
    sprintf(buff, "Sunrise %s  Noon %s  Sunset %s", jd2str(localTimeJD(Twilight.rise), true), b1, b2);
    ph.boxString(buff, lw, lh);
    //ph.drawString(buff);
    ph.drawPrint((MAX_ROW - lw) / 2, 295, buff);
  } else {
    if (Twilight.polar == 1) sprintf(buff, "circumpolar, above the horizon");
    else sprintf(buff, "circumpolar, bellow the horizon");
    ph.boxString(buff, lw, lh);
    //ph.drawString(buff);
    ph.drawPrint((MAX_ROW - lw) / 2, 295, buff);
  }
}

void gPrintData(void) {
  drawDisp ph(&myDisp, Font09, foreColor, backColor);
  myDisp.dumpImage(268, 40, &thermoImage);
  myDisp.dumpImage(273, 40 + 64 + 5, &umiImage);
  myDisp.dumpImage(259 + 5, 40 + (64 + 5) * 2, &pressImage);
  //drawDisp pSb(&myDisp, &FreeMonoBold9pt7b, foreColor, backColor);
  //ph.drawString("mbar");
  ph.drawPrint(330 + 35, 185 + 40, "mbar");
}

const time_t TIME_2010_01_01 = 1262304000;

void PrintLineRS(drawDisp* pS, char* s) {
  Serial.printf("%s", s);
  pS->printLine(s);
}



void DispBrightness(int v) {  // v = 0..100
  float vl = (255.0 * v) / 100.0;
  vl = (vl > 255 ? 255 : vl);
  vl = (vl < 0 ? 0 : vl);
  ledcWrite(PIN_DISP_LED, (int)vl);
}

void initData(void) {
  uint8_t* s = (uint8_t*)&DataPrg;
  for (int i = 0; i < sizeof(DataPrg); i++, s++) *s = 0;
  strcpy(DataPrg.ssid, "");
  strcpy(DataPrg.password, "");
  DataPrg.lat = 41.8;
  DataPrg.log = 12.5;
  DataPrg.height = 0;
  DataPrg.utcOffset = 3600;
  DataPrg.TyDaylight = 2;
  DataPrg.StartWork = 0;
  DataPrg.OnWifi = true;
  DataPrg.Vol = 100;  // 0..200
  DataPrg.onSoundBell = true;
  DataPrg.onSoundCucu = true;
  DataPrg.hourStartSound = 8.50 * 3600;
  DataPrg.hourEndSound = 20.0 * 3600;
  DataPrg.hourAlarm = 9.5 * 3600;
  DataPrg.AlarmOn = true;
  DataPrg.OffAlarmWeek = false;   // Se false sveglia off del weekend
  DataPrg.nCycleAlarm = 2;        // numero di ripetizione allarme; se è 0 alarm off
  DataPrg.longRingSec = 30;       // durata della sveglia
  DataPrg.longRipAlarmSec = 120;  // l'allarma è ripetuto dopo longRipAlarmSec se non stop
}

static waitTimer tmDisp(180 * 1000);  // display al massimo della luminosita per x sec dopo press button

void dataInitialize(void) {
  static int setEditV = 1;
  static int OffMenu = 1;
  uint32_t tButt;
  while (OffMenu) {
    bool onButton = onButtonQueque(tButt);
    OffMenu = SetEditVarWeb(setEditV, onButton, tButt, 0);
    delay(100);
  }
}

void offWiFi(void) {
  WiFi.disconnect(true);
  delay(100);
  WiFi.mode(WIFI_OFF);
}

char* ReadIp(void) {
  static char buff[64];
  if (WiFi.status() == WL_CONNECTED) sprintf(buff, "WiFi IP: %s  RSSI %d dBm", WiFi.localIP().toString().c_str(), WiFi.RSSI());
  return buff;
}

void stopPlaySound(void) {
  if (InRunMp3()) {
    while (!CloseMp3File()) RunMP3();
    while (InRunMp3()) RunMP3();
  }
}

void startPlaySoundAlr(void) {
  stopPlaySound();
  OpenMp3File(NAME_FILE_ALARM_CLOCK, 10);  // si ripete 10+1 volte circa 135 secondi
}
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
void loop() {
  //static char buff[48];
  static waitTimer tmPlayBell(800);
  static waitTimer tmMinPlay(2000);
  static waitTimer tmRunAllarm(DataPrg.longRingSec * 1000);      // durata della sveglia
  static waitTimer tmRipAllarm(DataPrg.longRipAlarmSec * 1000);  // l'allarma è ripetuto dopo longRipAlarmSec se non stop
  static waitTimer tmRetFrMenu(600 * 1000);                      // ritorna al menu principale
  static cAverage mdLux(10);
  static time_t tEverySec = 0;
  static int tEveryHour = -1;
  static int tEveryMin = -1;
  static int attMenu = MENU_CLOCK;
  static int memAttMenu = MENU_CLOCK;
  static bool clearButtOnDisp = false;
  static int act = 0;
  static int cNButt = 0;     // conta il numero di volte che butt e' pressed, si azzera con tmPlayBell
  static int bRunAlarm = 0;  // se true allarme in run
  static int nCyAlarm = 0;   // conta il numero di ripetizione delle allarme
  bool onSec, onMin, onHour;
  time_t tm, ltm;
  static int setEditV = 0;
  static int OffMenu = 0;
  static int setEditWeb = 0;


  tm = nowTime();
  ltm = localTime(tm);

  RunMP3();

  mdLux.pushValue(dig2Volt(analogRead(PIN_PHOTO_R)));

  uint32_t tButt;
  bool onButton = onButtonQueque(tButt);

  // static int stato = 0;
  // if (stato) {
  //   stopPlaySound();
  //   OffMenu = SetEditVarWeb(stato, onButton, tButt, ltm);
  //   //OffMenu = SetEditVar(stato, onButton, tButt);
  //   if (!OffMenu) {
  //     stato = 0;
  //     //ForceCheckWiFi = true;
  //   }
  // }


  if (setEditV) {
    uint32_t otButt = tButt;
    if (InRunMp3()) stopPlaySound();
    if (tButt >= TIME_SETVAR_MENU) {
      onButton = false;
      otButt = 0;
    }
    if (setEditWeb) OffMenu = SetEditVarWeb(setEditV, onButton, otButt, ltm);
    else OffMenu = SetEditVar(setEditV, onButton, otButt);
    tmDisp.start();
    clearButtOnDisp = true;
    if (!OffMenu) {
      setEditWeb = setEditV = 0;
      tEverySec = 0;
      tEveryHour = tEveryMin = -1;
      SetMp3Vol(DataPrg.Vol / 100.);
      //myDisp.clearScreen(backColor);
      setTimeClock();
      //SaveData();
      //ForceCheckWiFi = true;
    }
  }

  if (onButton && setEditV == 0 && setEditWeb == 1) setEditWeb = 0;

  if (tButt > 0) {
    if (!tmDisp.run() && valueBrightness(mdLux.retMd()) < 50) clearButtOnDisp = true;
    tmDisp.start();
    DispBrightness(100);
    //if (onButton) Serial.printf("Press Button %ld\n", tButt);
  } else act = 0;

  if (tmMinPlay.run()) clearQuequeButton();

  if (onButton && (bRunAlarm || (!tmMinPlay.run() && InRunMp3()))) {
    bRunAlarm = 0;
    Serial.println("Press button: stop Alarm/play");
    if (InRunMp3()) {
      clearButtOnDisp = true;
      stopPlaySound();
    }
  }


  int a = SelectTmButton(tButt, act);

  if (a) {
    clearButtOnDisp = true;
    if (attMenu != MENU_CLOCK) {
      tEverySec = 0;
      tEveryHour = tEveryMin = -1;
      if (a == 1) {
        attMenu--;
        if (attMenu < 0) attMenu = MENU_CLOCK;
      }
      if (a == 2) attMenu = MENU_CLOCK;
    }
    if (a == 3) setEditV = 1;
    if (a == 4) setEditWeb = setEditV = 1;
  }

  if (clearButtOnDisp && onButton) {
    onButton = clearButtOnDisp = false;
    tButt = 0;
  }


  if (!tmRetFrMenu.run()) {
    if (attMenu != MENU_CLOCK) {
      memAttMenu = attMenu;
      attMenu = MENU_CLOCK;
      tEverySec = 0;
      tEveryHour = tEveryMin = -1;
    }
  }

  if (onButton && !OffMenu) {
    //setEditWeb = 0;
    if (tmPlayBell.run()) cNButt += numInQuequeButton() + 1;
    else cNButt = 0;
    tmPlayBell.start();
    tEverySec = 0;
    tEveryHour = tEveryMin = -1;

    attMenu++;
    if (attMenu >= MENU_END) attMenu = MENU_CLOCK;

    if (memAttMenu != MENU_CLOCK) {
      attMenu = memAttMenu;
      memAttMenu = MENU_CLOCK;
    }
  }


  if (onButton && tButt > 0) tmRetFrMenu.start();


  if (!OffMenu && DataPrg.OnWifi) {
    int st = ntp.update();
    static bool eSt = false;
    if (st == NTP_ERR_WIFI_ERR) eSt = true;
    if (eSt) checkWiFiStatus();
    if (st == NTP_OK) {
      Serial.println("Sincronizzazione NTP avvenuta e time interno aggiornato!");
      tm = nowTime();
      ltm = localTime(tm);
      setDateTimeDs3231(tm);
      setTimeClock();
      offWiFi();
      eSt = false;
    }
  }

  if (attHour(ltm) != tEveryHour) {
    tEveryHour = attHour(ltm);
    setTimeClock();
    onHour = true;
  } else onHour = false;

  if (attMin(ltm) != tEveryMin) {
    tEveryMin = attMin(ltm);
    onMin = true;
  } else onMin = false;

  double v;
  if (ltm - tEverySec >= 1) {
    tEverySec = ltm;
    v = mdLux.retMd();
    //Serial.printf("%f %f\n",valueBrightness(v),valueLux(v));
    if (tmDisp.run()) DispBrightness(100);
    else DispBrightness((int)valueBrightness(v));
    onSec = true;
  } else onSec = false;


  if (AcqData(v)) {
    if (!ErrTemp) {
      tempAmb.putAcqData(tempExt);
      umiAmb.putAcqData(umiExt);
    }
    if (!ErrPress) pressAmb.putAcqData(pressExt);
  }

  if (!OffMenu) DispMenu(tm, attMenu, onSec, onMin, onHour);


  if (isAlarmClock(ltm) && DataPrg.nCycleAlarm && bRunAlarm == 0 && !OffMenu) {
    startPlaySoundAlr();
    //tmMinPlay.start();
    tmRunAllarm.start(DataPrg.longRingSec * 1000);
    bRunAlarm = 1;
    nCyAlarm = 0;
    Serial.printf("Start alarm\n");
  }
  //if (bRunAlarm) Serial.printf("%d %d %d %d\n",tmRunAllarm.run(),tmRipAllarm.run(),bRunAlarm, nCyAlarm);

  if (bRunAlarm == 1 && !tmRunAllarm.run()) {
    stopPlaySound();
    tmRipAllarm.start(DataPrg.longRipAlarmSec * 1000);
    nCyAlarm++;
    if (nCyAlarm >= DataPrg.nCycleAlarm) bRunAlarm = 0;
    else bRunAlarm = 2;
    Serial.printf("Stop alarm\n");
  }

  if (bRunAlarm == 2 && !tmRipAllarm.run() && !tmRunAllarm.run()) {
    startPlaySoundAlr();
    //tmMinPlay.start();
    tmRunAllarm.start(DataPrg.longRingSec * 1000);
    bRunAlarm = 1;
    Serial.printf("Cycle alarm\n");
  }

  if ((isNoon(ltm) && checkokSound(ltm) && DataPrg.onSoundBell && !InRunMp3() && !OffMenu) || cNButt > NUM_PRESS_BUTT_ON_BELL) {
    playBell();
    if (cNButt) clearQuequeButton();
    cNButt = 0;
    tmMinPlay.start();
  }

  if (DataPrg.onSoundCucu && !isNoon(ltm) && checkokSound(ltm) && !InRunMp3() && ltm % 3600 == 0 && !OffMenu) {
    OpenMp3File(NAME_FILE_CUCU_PLAY);
    //tmMinPlay.start();
  }
}

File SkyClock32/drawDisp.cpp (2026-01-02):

#include "drawDisp.h"
#include <pgmspace.h>


#define pgm_read_pointer(addr) ((void *)pgm_read_dword(addr))

inline GFXglyph *pgm_read_glyph_ptr(const GFXfont *gfxFont, uint8_t c) {
  return &(((GFXglyph *)pgm_read_pointer(&gfxFont->glyph))[c]);
}

inline uint8_t *pgm_read_bitmap_ptr(const GFXfont *gfxFont) {
  return (uint8_t *)pgm_read_pointer(&gfxFont->bitmap);
}

void drawDisp::setColor(uint16_t _color, uint16_t _bkcolor) {
  color[pBuff] = _color;
  bkcolor = _bkcolor;
}


void drawDisp::clrbuff(void) {
  pBuff = nBuff = 0;
  for (int i = 0; i < MAXCANVAS; i++) {
    buff[i] = NULL;
    ox[i] = oy[i] = lx[i] = ly[i] = stride[i] = 0;
    priority[i] = -1;
  }
}

drawDisp::drawDisp(display *_disp, const GFXfont *gfx_Font, uint16_t _color, uint16_t _bkcolor, const char *_charReduction) {
  baseline = lyfont = 0;
  disp = _disp;
  charReduction = _charReduction;
  clrbuff();
  setColor(_color, _bkcolor);
  setFont(gfx_Font);
}

drawDisp::drawDisp(display *_disp, const GFXfont *gfx_Font, uint16_t _color, uint16_t _bkcolor, uint16_t _lx, uint16_t _ly, const char *_charReduction) {
  drawDisp(_disp, gfx_Font, _color, _bkcolor, _charReduction);
  creatCanvas(_lx, _ly);
}

drawDisp::~drawDisp() {
  for (int i = 0; i < MAXCANVAS; i++)
    if (buff[i]) delete (buff[i]);
}


void drawDisp::setPixel(uint16_t _x, uint16_t _y, bool v) {

  if (!buff[pBuff]) return;
  uint16_t x = _x - ox[pBuff];
  uint16_t y = _y - oy[pBuff];
  if (x >= lx[pBuff] || y >= ly[pBuff]) return;
  uint32_t idx = y * stride[pBuff] + (x >> 3);
  uint8_t mask = 0x80 >> (x & 7);
  if (v) buff[pBuff][idx] |= mask;
  else buff[pBuff][idx] &= ~mask;
}

bool drawDisp::getPixel(uint16_t _x, uint16_t _y) {
  if (!buff[pBuff]) return false;
  uint16_t x = _x - ox[pBuff];
  uint16_t y = _y - oy[pBuff];
  if (x >= lx[pBuff] || y >= ly[pBuff]) return false;
  uint32_t idx = y * stride[pBuff] + (x >> 3);
  uint8_t mask = 0x80 >> (x & 7);
  if (buff[pBuff][idx] & mask) return true;
  return false;
}

void drawDisp::setFont(const GFXfont *gfx_Font) {
  gfxFont = gfx_Font;
  GFXglyph *glyph;
  yAdvance = pgm_read_byte(&gfxFont->yAdvance);
  nChar = pgm_read_byte(&gfxFont->last) - pgm_read_byte(&gfxFont->first);
  int16_t mm = 0, mx = 0;
  int8_t yo;
  for (uint8_t i = 0; i < nChar; i++) {
    glyph = pgm_read_glyph_ptr(gfxFont, i);
    yo = pgm_read_byte(&glyph->yOffset);
    mm = (mm > yo ? yo : mm);
    mx = (mx < yo ? yo : mx);
  }
  baseline = -mm;
  lyfont = mx - mm + 1;
  //Serial.printf("mm=%d mx=%d n=%d bs=%d ly=%d\n", mm, mx, nChar, baseline, lyfont);
}

void drawDisp::drawLine(int16_t x0, int16_t y0, int16_t x1, int16_t y1, int16_t thickness, int16_t lenDash) {
  if (thickness < 1) return;  // Spessore minimo 1 pixel

  int dx = abs(x1 - x0), sx = x0 < x1 ? 1 : -1;
  int dy = -abs(y1 - y0), sy = y0 < y1 ? 1 : -1;
  int err = dx + dy, e2;
  int count = 0;
  bool onDash = true;

  // Caso speciale: linea di spessore 1 (comportamento originale)
  if (thickness == 1) {
    while (1) {
      if (onDash) setPixel(x0, y0);
      if (x0 == x1 && y0 == y1) break;

      if (lenDash) {
        count++;
        if (count == lenDash) {
          count = 0;
          onDash = !onDash;
        }
      }

      e2 = 2 * err;
      if (e2 >= dy) {
        err += dy;
        x0 += sx;
      }
      if (e2 <= dx) {
        err += dx;
        y0 += sy;
      }
    }
    return;
  }

  // Caso linee più spesse (thickness >= 2)
  // Calcola la direzione perpendicolare per lo spessore
  int perpX, perpY;

  // Determina la direzione dominante per il calcolo della perpendicolare
  if (dx >= abs(dy)) {
    // Linea più orizzontale - perpendicolare verticale
    perpX = 0;
    perpY = 1;
  } else {
    // Linea più verticale - perpendicolare orizzontale
    perpX = 1;
    perpY = 0;
  }

  int halfThickness = thickness / 2;
  int thicknessOffset = (thickness % 2 == 0) ? 1 : 0;  // Compensazione per spessori pari

  while (1) {
    if (onDash) {
      // Disegna tutti i pixel dello spessore richiesto
      for (int i = -halfThickness; i < halfThickness + thicknessOffset; i++) {
        int px = x0 + i * perpX;
        int py = y0 + i * perpY;
        setPixel(px, py);
      }
    }

    if (x0 == x1 && y0 == y1) break;

    if (lenDash) {
      count++;
      if (count == lenDash) {
        count = 0;
        onDash = !onDash;
      }
    }

    e2 = 2 * err;
    if (e2 >= dy) {
      err += dy;
      x0 += sx;
    }
    if (e2 <= dx) {
      err += dx;
      y0 += sy;
    }
  }
}



// Disegna un cerchio con algoritmo di Bresenham
void drawDisp::drawCircle(int16_t cx, int16_t cy, int16_t r) {
  int x = r;
  int y = 0;
  int err = 0;
  while (x >= y) {
    setPixel(cx + x, cy + y);
    setPixel(cx + y, cy + x);
    setPixel(cx - y, cy + x);
    setPixel(cx - x, cy + y);
    setPixel(cx - x, cy - y);
    setPixel(cx - y, cy - x);
    setPixel(cx + y, cy - x);
    setPixel(cx + x, cy - y);
    y++;
    if (err <= 0) {
      err += 2 * y + 1;
    } else {
      x--;
      err += 2 * (y - x + 1);
    }
  }
}

void drawDisp::drawHorizontalLine(int16_t x1, int16_t x2, int16_t y, int16_t lenDash) {
  int16_t count = 0;
  bool onDash = true;
  if (y<0 || y>=ly[pBuff]) return;
  for (int16_t x = x1; x <= x2; x++) {
    if (onDash) setPixel(x, y);
    if (lenDash) {
      count++;
      if (count == lenDash) {
        count = 0;
        onDash = !onDash;
      }
    }
  }
}
void drawDisp::drawVerticalLine(int16_t x, int16_t y1, int16_t y2, int16_t lenDash) {
  int16_t count = 0;
  bool onDash = true;
  if (x<0 || x>=lx[pBuff]) return;
  for (int16_t y = y1; y <= y2; y++) {
    if (onDash) setPixel(x, y);
    if (lenDash) {
      count++;
      if (count == lenDash) {
        count = 0;
        onDash = !onDash;
      }
    }
  }
}

void drawDisp::drawFilledCircle(int16_t x0, int16_t y0, int16_t r) {
  int x = r;
  int y = 0;
  int err = 0;

  while (x >= y) {
    // Disegna le linee orizzontali per tutti gli ottanti
    drawHorizontalLine(x0 - x, x0 + x, y0 + y);
    drawHorizontalLine(x0 - x, x0 + x, y0 - y);
    drawHorizontalLine(x0 - y, x0 + y, y0 + x);
    drawHorizontalLine(x0 - y, x0 + y, y0 - x);

    y++;
    err += 1 + 2 * y;
    if (2 * (err - x) + 1 > 0) {
      x--;
      err += 1 - 2 * x;
    }
  }
}
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
